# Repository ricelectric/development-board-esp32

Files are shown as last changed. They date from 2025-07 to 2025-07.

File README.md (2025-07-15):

# development-board-esp32

This is an open source repository for a development board featuring ESP32-C3, perfect for IoT projects. More information is available [here](https://qiita.com/ricelectric/items/990088bb8d065cbd0641).

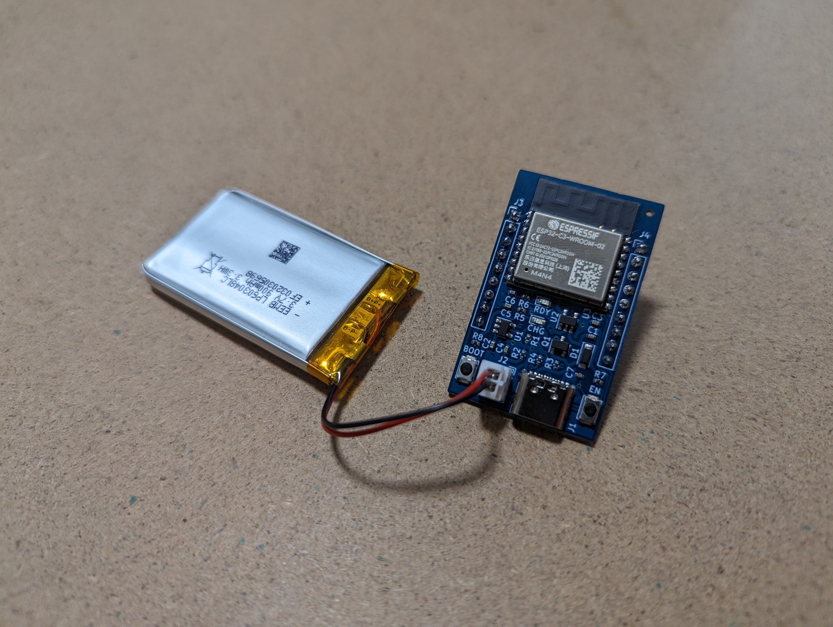
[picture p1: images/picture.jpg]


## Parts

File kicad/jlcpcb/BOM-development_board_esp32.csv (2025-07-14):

Comment | Designator | Footprint | LCSC
EN | SW1,SW2 | SW_Push_SPST_NO_Alps_SKRK | C115357
AO3401A | Q1 | SOT-23 | C15127
10u | C2,C3,C5 | C_0402_1005Metric | C15525
CHG | D2,D3 | LED_0603_1608Metric | C2286
4.7u | C1,C4 | C_0402_1005Metric | C23733
470 | R5,R6 | R_0402_1005Metric | C25117
100k | R2 | R_0402_1005Metric | C25741
10k | R7,R8 | R_0402_1005Metric | C25744
3.3k | R1 | R_0402_1005Metric | C25890
5.1k | R3,R4 | R_0402_1005Metric | C25905
0.1u | C6,C7 | C_0402_1005Metric | C307331
USB-C | J1 | USB_C_Receptacle_XKB_U262-16XN-4BVC11 | C319148
MCP73831-2-OT | U1 | SOT-23-5 | C424093
AP2112K-3.3 | U2 | SOT-23-5 | C51118
B5819W | D1 | D_SOD-123 | C8598
Conn_01x09 | J4 | PinHeader_1x09_P2.54mm_Vertical
ESP32-C3-WROOM-02 | U3 | ESP32-C3-WROOM-02
Conn_01x09 | J3 | PinHeader_1x09_P2.54mm_Vertical
Conn_01x02 | J2 | JST_PH_B2B-PH-K_1x02_P2.00mm_Vertical

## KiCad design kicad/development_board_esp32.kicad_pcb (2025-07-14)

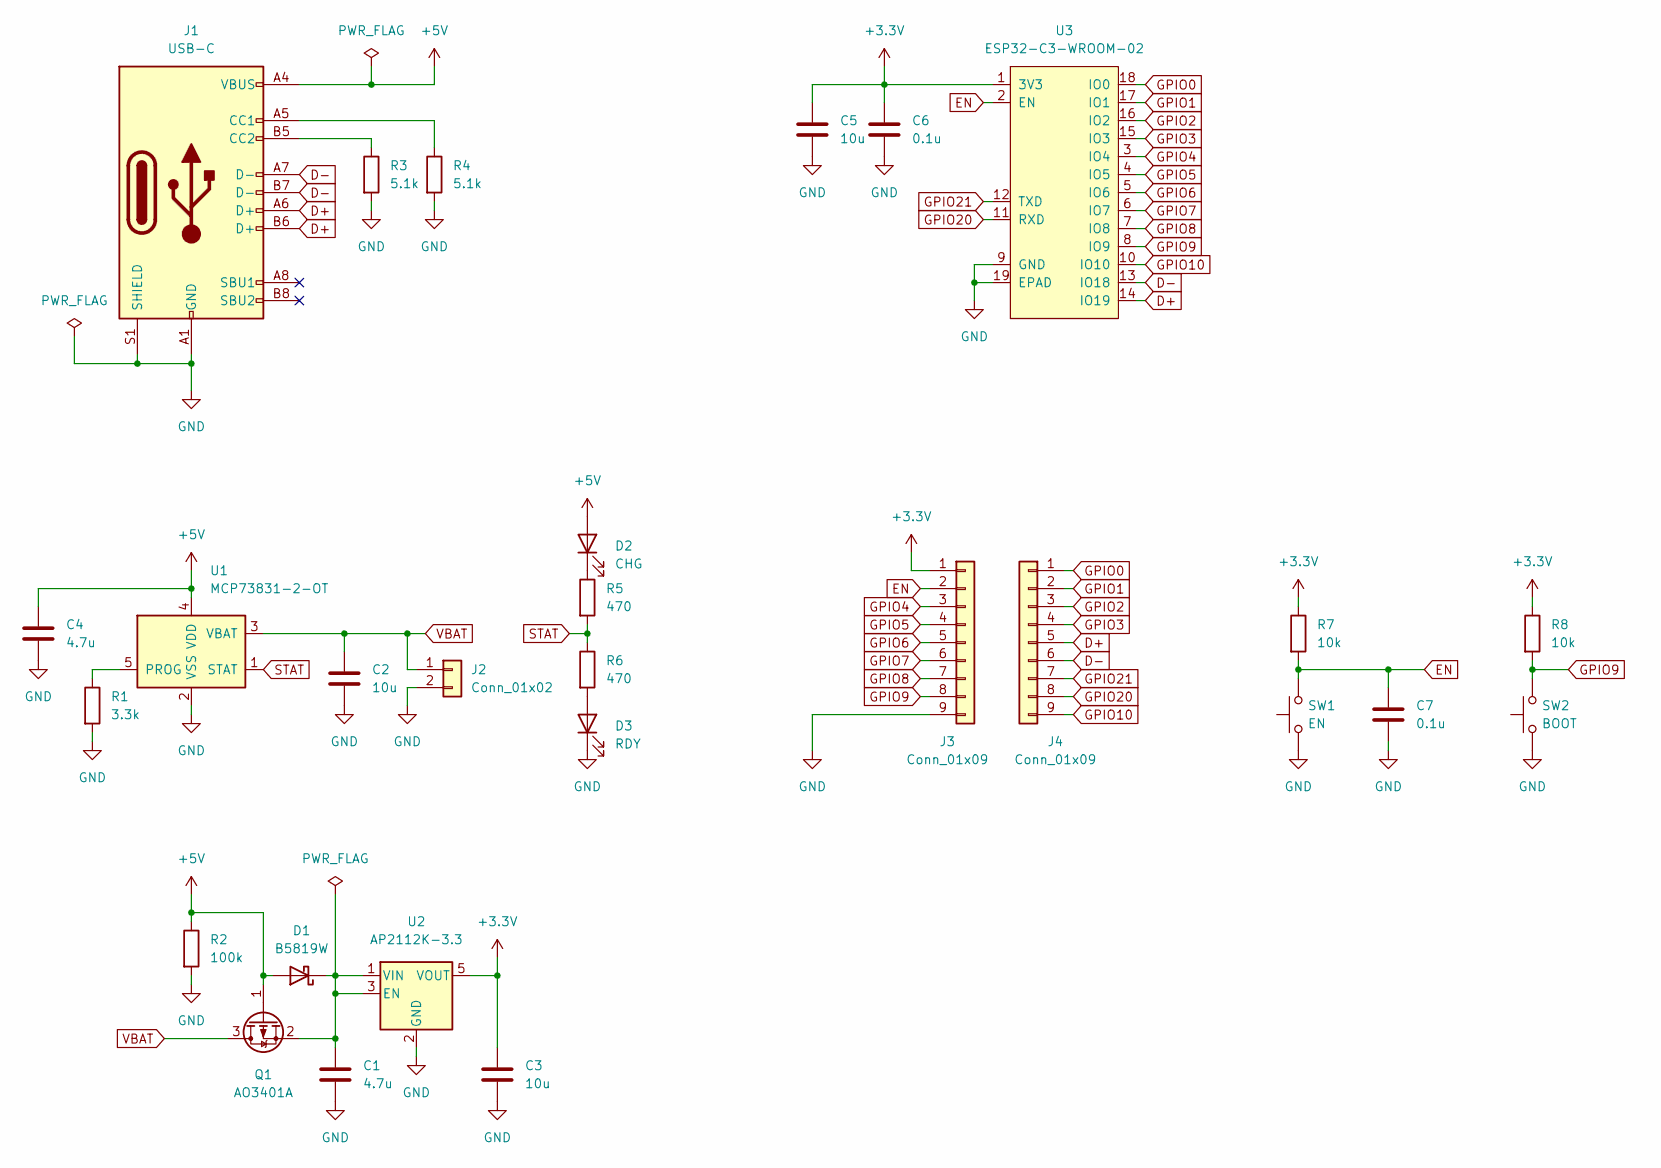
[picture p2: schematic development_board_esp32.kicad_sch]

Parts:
C1, C4: 4.7u; C_0402_1005Metric
C2, C3, C5: 10u; C_0402_1005Metric
C6, C7: 0.1u; C_0402_1005Metric
D1: B5819W; D_SOD-123
D2: CHG; LED_0603_1608Metric
D3: RDY; LED_0603_1608Metric
J1: USB-C; USB_C_Receptacle_XKB_U262-16XN-4BVC11
J2: Conn_01x02; JST_PH_B2B-PH-K_1x02_P2.00mm_Vertical
J3, J4: Conn_01x09; PinHeader_1x09_P2.54mm_Vertical
Q1: AO3401A; SOT-23
R1: 3.3k; R_0402_1005Metric
R2: 100k; R_0402_1005Metric
R3, R4: 5.1k; R_0402_1005Metric
R5, R6: 470; R_0402_1005Metric
R7, R8: 10k; R_0402_1005Metric
SW1: EN; SW_Push_SPST_NO_Alps_SKRK
SW2: BOOT; SW_Push_SPST_NO_Alps_SKRK
U1: MCP73831-2-OT; SOT-23-5
U2: AP2112K-3.3; SOT-23-5
U3: ESP32-C3-WROOM-02

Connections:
+3.3V: C3.1, C5.1, C6.1, J3.1, R7.1, R8.1, U2.5 (VOUT), U3.1 (3V3)
+5V: C4.1, D1.2 (A), D2.2 (A), J1.A4 (VBUS), J1.A9 (VBUS), J1.B4 (VBUS), J1.B9 (VBUS), Q1.1 (G), R2.1, U1.4 (VDD)
D+: J1.A6 (D+), J1.B6 (D+), J4.5, U3.14 (IO19)
D-: J1.A7 (D-), J1.B7 (D-), J4.6, U3.13 (IO18)
EN: C7.1, J3.2, R7.2, SW1.2, U3.2 (EN)
GND: C1.2, C2.2, C3.2, C4.2, C5.2, C6.2, C7.2, D3.1 (K), J1.A1 (GND), J1.A12 (GND), J1.B1 (GND), J1.B12 (GND), J1.S1 (SHIELD), J2.2, J3.9, R1.2, R2.2, R3.2, R4.2, SW1.1, SW2.1, U1.2 (VSS), U2.2 (GND), U3.9 (GND), U3.19 (EPAD)
GPIO0: J4.1, U3.18 (IO0)
GPIO1: J4.2, U3.17 (IO1)
GPIO2: J4.3, U3.16 (IO2)
GPIO3: J4.4, U3.15 (IO3)
GPIO4: J3.3, U3.3 (IO4)
GPIO5: J3.4, U3.4 (IO5)
GPIO6: J3.5, U3.5 (IO6)
GPIO7: J3.6, U3.6 (IO7)
GPIO8: J3.7, U3.7 (IO8)
GPIO9: J3.8, R8.2, SW2.2, U3.8 (IO9)
GPIO10: J4.9, U3.10 (IO10)
GPIO20: J4.8, U3.11 (RXD)
GPIO21: J4.7, U3.12 (TXD)
unnamed: C1.1, D1.1 (K), Q1.2 (S), U2.1 (VIN), U2.3 (EN)
unnamed: D2.1 (K), R5.1
unnamed: D3.2 (A), R6.2
unnamed: J1.A5 (CC1), R4.1
unnamed: J1.B5 (CC2), R3.1
unnamed: R1.1, U1.5 (PROG)
STAT: R5.2, R6.1, U1.1 (STAT)
VBAT: C2.1, J2.1, Q1.3 (D), U1.3 (VBAT)

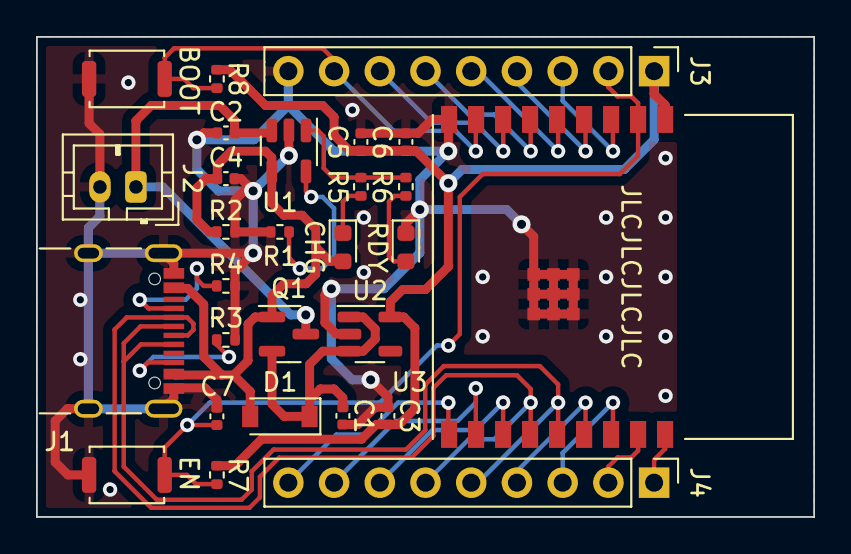
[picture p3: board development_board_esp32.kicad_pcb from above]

Board: 2 copper layers, 43.2 x 26.7 mm, 28 parts (0 on the bottom side), 27 nets.
